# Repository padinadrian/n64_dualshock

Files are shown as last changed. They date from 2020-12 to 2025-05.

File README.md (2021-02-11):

# N64/DualShock

Author: Adrian Padin (padin.adrian@gmail.com)

Last updated: December 13, 2020

## Introduction

This repo contains the results of my work attempting to use a PlayStation 2 DualShock 2 controller with a Nintendo 64.

I used an [Adafruit Trinket Mini](https://learn.adafruit.com/introducing-trinket) to read from the DualShock controller, remap the buttons, and send the data to the N64.

Some of the tasks I accomplished along the way:

* Implementing the beginnings of a SPI library for the Trinket using the Atmel USI (Universal Serial Interface).

* Using bit-banging to read and write from the N64 using the N64's unique single-wire interface.

* Reprogramming the Trinket to use a modified bootloader which allows it to boot much faster.

You can read more about the N64, SPI, and other topics by checking out the resources below.

## Prototype

This is a picture of the prototype device:

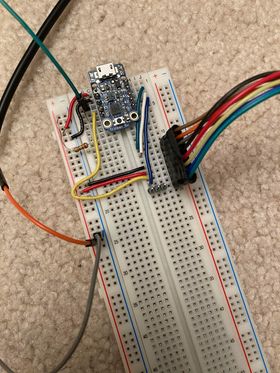
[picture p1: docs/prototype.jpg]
Prototype


Pin mapping:
* #0 - MISO (DualShock controller data)
* #1 - MOSI (DualShock controller command)
* #2 - SCLK (DualShock controller clock)
* #3 - SSEL (DualShock controller select)
* #4 - N64 data in/out

Here's a brief description of what's happening here:

* On the left, we have the power and ground lines. These are connected directly to the N64 controller's power, which is at 3.3V. This power line is fed into the VBAT pin on the Trinket. (In my prototype I used a 5V Trinket but I haven't noticed any issues).

* There are two GPIO pins on the left side of the board: #4 is used to communicate with the N64 and has a 22k pull-up resistor tied to the power line (since the N64 protocol is open-collector); and #3 (yellow wire in the picture) is the SPI select line.

* The three pins on the right side (green, white, and blue) are MISO, MOSI, and SCLK respectively. These connect to the PS2 controller, which is the large black connector on the bottom right.

## Resources

#### N64 Controller

In order to interface with the N64 I had to program the Trinket to behave like an N64 controller. Since the N64 uses such an odd custom protocol I used code from an [Instructables tutorial by quasse](https://www.instructables.com/Use-an-Arduino-with-an-N64-controller/) for reference.

(I did not copy the code directly since it is designed for interfacing with a controller, not the N64 console itself.)

There's also a great [tutorial by qwertymodo.com](http://www.qwertymodo.com/hardware-projects/n64/n64-controller) on reverse-engineering the N64 protocol which was very insightful, especially when it came to the data layer and remapping the button and joystick data.

#### PlayStation 2 / DualShock 2

I have lots of information on the PS2 controller in my `embedded_tools` library (see below).

#### embedded_tools

The embedded_tools library is a collection of convenient C++ utilities and libraries that I use across several of my projects. I'm continually developing it and adding functionality as I need it, but if you would like to use any part of it or contribute, you are more than welcome.

You can check out the [Github repository](https://github.com/padinadrian/embedded_tools) for more details.

#### ATTiny85 Bootloader

One of the issues I ran into in this project was boot time - the built-in Trinket firmware contains a bootloader that can take several seconds to boot, because it is searching for a USB connection to allow it to upload sketches.

After some digging online I found a bootloader (created by adafruit user hiduino) that allows you to skip the boot process if waking from a cold start, and only enters the bootloader when pressing the reset button. This allowed my code to start running almost immediately (under 100ms) instead of taking 2-3 seconds.

* Repairing or replacing bootloader:
  [https://learn.adafruit.com/introducing-trinket/repairing-bootloader](https://learn.adafruit.com/introducing-trinket/repairing-bootloader)

* New bootloader image:
  [https://forums.adafruit.com/viewtopic.php?f=52&t=54218&p=376898&hilit=trinket+bootloader+skip#p376898](https://forums.adafruit.com/viewtopic.php?f=52&t=54218&p=376898&hilit=trinket+bootloader+skip#p376898)

## To-Do

* Allow an attachable PS2 controller (instead of broken-out cheap controller).
  * https://www.amazon.com/PS2-Controller-Extension-Cable-Playstation-2/dp/B00005MDZ1

* Put together a more sturdy setup (PCB? or solder board?).

* Make a case (3D-printed maybe).

* Refactor and migrate N64-related code back into `embedded_tools`.

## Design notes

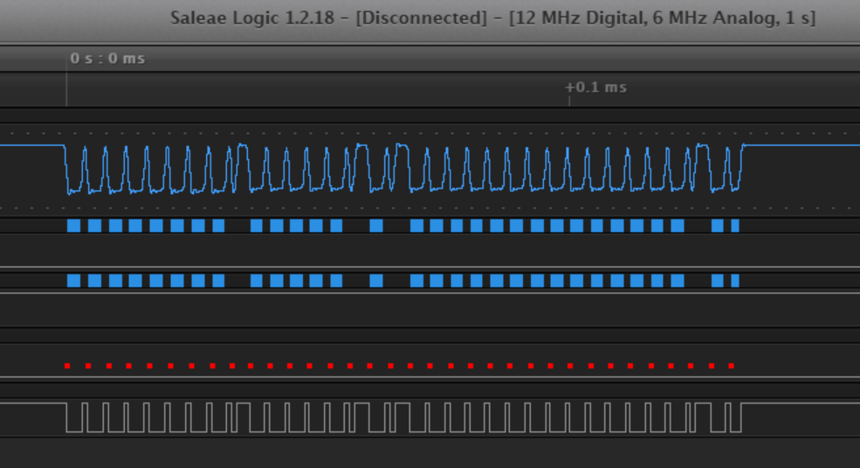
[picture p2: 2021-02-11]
docs/Captures/n64_oem_poll.png

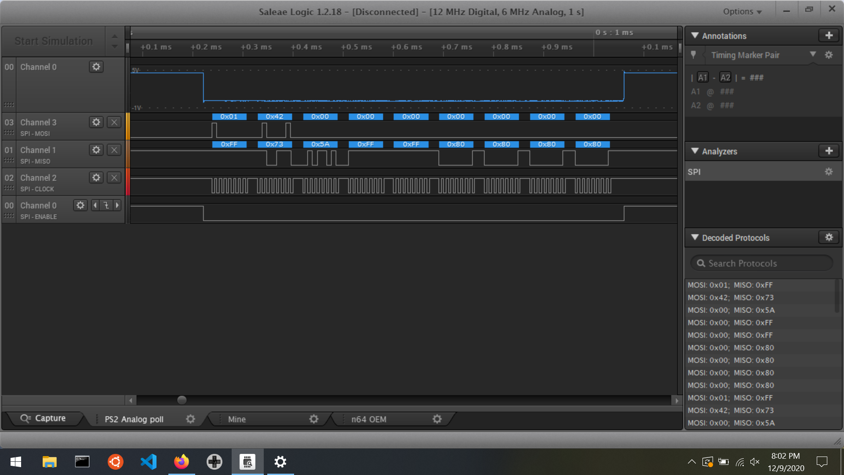
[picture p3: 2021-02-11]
docs/Captures/ps2_official.png

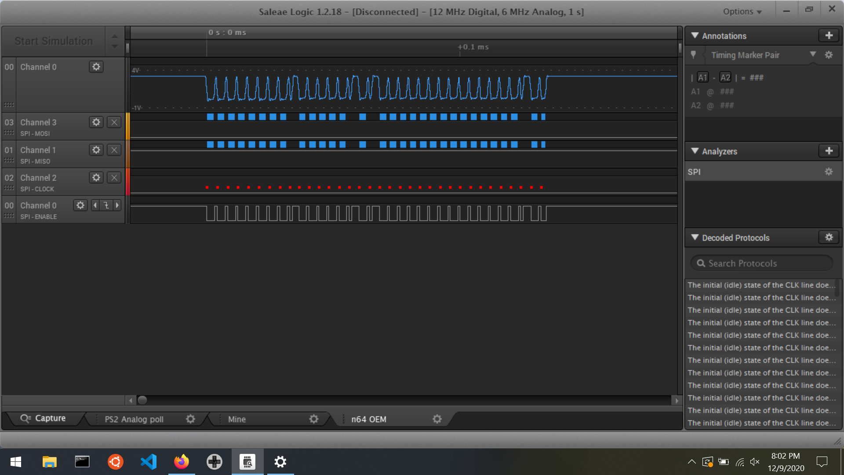
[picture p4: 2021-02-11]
docs/Captures/official.png

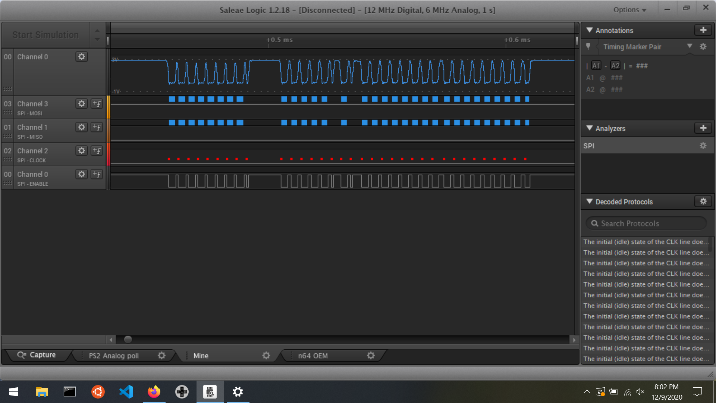
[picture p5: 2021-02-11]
docs/Captures/mine.png

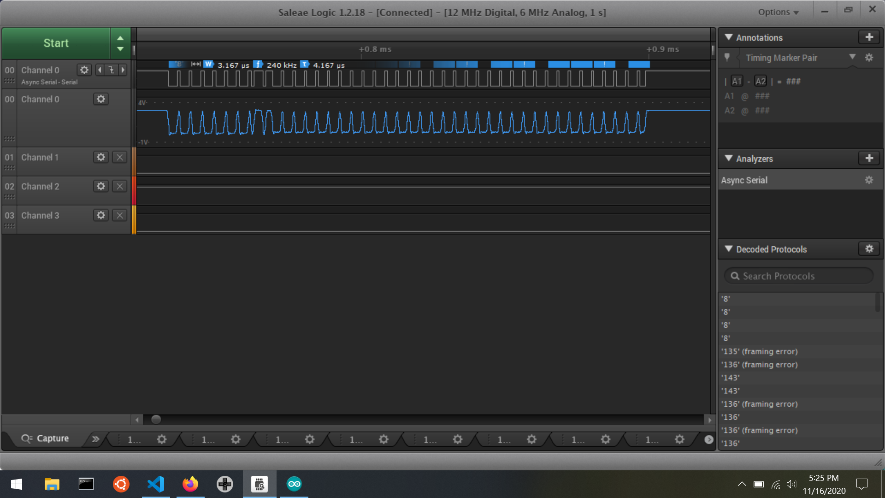
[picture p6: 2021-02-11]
docs/Captures/N64_screenshot1.png

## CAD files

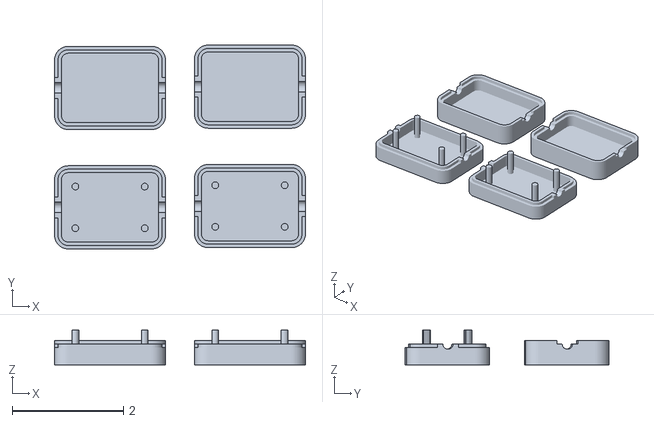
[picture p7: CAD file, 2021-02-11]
N64 DualShock (Final, inches).stl
4.52 x 3.67 x 0.625

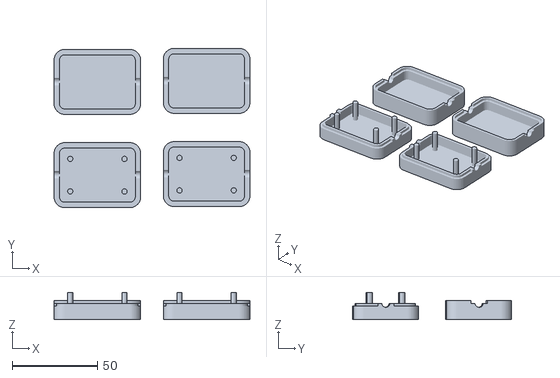
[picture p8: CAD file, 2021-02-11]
N64 DualShock (Final, millimeters).stl
114.8 x 93.3 x 15.9

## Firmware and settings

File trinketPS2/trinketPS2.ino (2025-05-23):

/**
 * File:    n64_dualshock.ino
 * Author:  padin.adrian@gmail.com
 *
 * Copyright 2019
 */

/* ===== Includes ====== */
#include "C:\\Users\\apadi\\Documents\\projects\\n64_dualshock\\trinketPS2\\button_translate.hpp"
#include "C:\\Users\\apadi\\Documents\\projects\\n64_dualshock\\trinketPS2\\N64.hpp"
#include "C:\\Users\\apadi\\Documents\\projects\\n64_dualshock\\embedded_tools/gpio/adrian_gpio_arduino.hpp"
#include "C:\\Users\\apadi\\Documents\\projects\\n64_dualshock\\embedded_tools/spi/adrian_spi_trinket.hpp"
#include "C:\\Users\\apadi\\Documents\\projects\\n64_dualshock\\embedded_tools/ps2/adrian_dualshock.hpp"
#include "C:\\Users\\apadi\\Documents\\projects\\n64_dualshock\\embedded_tools/n64/adrian_n64_console.hpp"

/* ===== Global ===== */

static adrian::TrinketSPI spi;
static adrian::ArduinoGPIO spi_select(3);
static adrian::DualShock controller(&spi, &spi_select);


/* ===== SETUP ===== */

void setup()
{
    spi_select.SetPinMode(OUTPUT);
    spi_select.Write(0);

    SingleWireInit();

    controller.EnableAnalog();
}


/* ===== LOOP ===== */

#define OUTPUT_BUFSIZE 4

static uint8_t input_buf = 0;
static uint8_t output_buf[OUTPUT_BUFSIZE] = { 0 };

static adrian::DualShock::ButtonState ps2_buttons;
static adrian::N64Controller::ButtonState n64_buttons;

static uint8_t status_buf[3] = { 0x05, 0x00, 0x02 };
static uint8_t read_response[33] = { 0 };

void loop()
{
    bool read_controller = false;

    noInterrupts();

    // Respond to commands from N64
    if (SingleWireRead(&input_buf, 1)) {
        switch (input_buf) {
            // Status
            case 0x00: {
                status_buf[1] = 0;
                SingleWireWrite(status_buf, sizeof(status_buf));
                read_controller = true;
                break;
            }
            // Poll
            case 0x01: {
                // output_buf[1] = input_buf;
                SingleWireWrite((uint8_t*)(&n64_buttons), sizeof(n64_buttons));
                read_controller = false;
                break;
            }
            // Read
            case 0x02: {
                SingleWireWrite(read_response, sizeof(read_response));
                break;
            }
            // Write
            case 0x03: {
                // TODO
                break;
            }
            default: {
                break;
                // This is for debugging SingleWireRead.
                // Echo back what you thought the command was.
                status_buf[1] = input_buf;
                SingleWireWrite(status_buf, sizeof(status_buf));
                break;
            }
        }
    }

    interrupts();

    // Poll from PS2 controller
    if (!controller.IsAnalogEnabled()) {
        controller.EnableAnalog();
    }
    else if (read_controller) {
        controller.Poll(ps2_buttons);
        read_controller = false;
    }

    if (ps2_buttons.analog_valid) {
        adrian::TranslateButtons(ps2_buttons, n64_buttons);
    }
    else {
        // Set all buttons and joysticks to zero
        memset((void *)(&n64_buttons), 0, sizeof(n64_buttons));
    }
}

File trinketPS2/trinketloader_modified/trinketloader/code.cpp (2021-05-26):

#include "optiLoader.h"

/*
 * Bootload images.
 * These are the intel Hex files produced by the optiboot makefile,
 * with a small amount of automatic editing to turn them into C strings,
 * and a header attched to identify them
 */

extern image_t *images[];
extern uint8_t NUMIMAGES;

/*
 * readSignature
 * read the bottom two signature bytes (if possible) and return them
 * Note that the highest signature byte is the same over all AVRs so we skip it
 */

uint16_t readSignature (void)
{
  SPI.setClockDivider(CLOCKSPEED_FUSES);

  uint16_t target_type = 0;
  Serial.print("\nReading signature:");

  target_type = spi_transaction(0x30, 0x00, 0x01, 0x00);
  target_type <<= 8;
  target_type |= spi_transaction(0x30, 0x00, 0x02, 0x00);

  Serial.println(target_type, HEX);
  if (target_type == 0 || target_type == 0xFFFF) {
    if (target_type == 0) {
      Serial.println("  (no target attached?)");
    }
  }
  return target_type;
}

/*
 * findImage
 *
 * given 'signature' loaded with the relevant part of the device signature,
 * search the hex images that we have programmed in flash, looking for one
 * that matches.
 */
image_t *findImage (uint16_t signature)
{
  image_t *ip;
  Serial.println("Searching for image...");

  for (byte i=0; i < NUMIMAGES; i++) {
    ip = images[i];

    if (ip && (pgm_read_word(&ip->image_chipsig) == signature)) {
	Serial.print("  Found \"");
	flashprint(&ip->image_name[0]);
	Serial.print("\" for ");
	flashprint(&ip->image_chipname[0]);
	Serial.println();

	return ip;
    }
  }
  Serial.println(" Not Found");
  return 0;
}

/*
 * programmingFuses
 * Program the fuse/lock bits
 */
boolean programFuses (const byte *fuses)
{
  SPI.setClockDivider(CLOCKSPEED_FUSES);

  byte f;
  Serial.print("\nSetting fuses");

  f = pgm_read_byte(&fuses[FUSE_PROT]);
  if (f) {
    Serial.print("\n  Set Lock Fuse to: ");
    Serial.print(f, HEX);
    Serial.print(" -> ");
    Serial.print(spi_transaction(0xAC, 0xE0, 0x00, f), HEX);
  }
  f = pgm_read_byte(&fuses[FUSE_LOW]);
  if (f) {
    Serial.print("  Set Low Fuse to: ");
    Serial.print(f, HEX);
    Serial.print(" -> ");
    Serial.print(spi_transaction(0xAC, 0xA0, 0x00, f), HEX);
  }
  f = pgm_read_byte(&fuses[FUSE_HIGH]);
  if (f) {
    Serial.print("  Set High Fuse to: ");
    Serial.print(f, HEX);
    Serial.print(" -> ");
    Serial.print(spi_transaction(0xAC, 0xA8, 0x00, f), HEX);
  }
  f = pgm_read_byte(&fuses[FUSE_EXT]);
  if (f) {
    Serial.print("  Set Ext Fuse to: ");
    Serial.print(f, HEX);
    Serial.print(" -> ");
    Serial.print(spi_transaction(0xAC, 0xA4, 0x00, f), HEX);
  }
  Serial.println();
  return true;			/* */
}

/*
 * verifyFuses
 * Verifies a fuse set
 */
boolean verifyFuses (const byte *fuses, const byte *fusemask)
{
  SPI.setClockDivider(CLOCKSPEED_FUSES);
  byte f;
  Serial.println(F("Verifying fuses..."));
  f = pgm_read_byte(&fuses[FUSE_PROT]);
  if (f) {
    uint8_t readfuse = spi_transaction(0x58, 0x00, 0x00, 0x00);  // lock fuse
    readfuse &= pgm_read_byte(&fusemask[FUSE_PROT]);
    Serial.print(F("\tLock Fuse: ")); Serial.print(f, HEX);  Serial.print(" is "); Serial.println(readfuse, HEX);
    if (readfuse != f)
      return false;
  }
  f = pgm_read_byte(&fuses[FUSE_LOW]);
  if (f) {
    uint8_t readfuse = spi_transaction(0x50, 0x00, 0x00, 0x00);  // low fuse
    Serial.print(F("\tLow Fuse: 0x"));  Serial.print(f, HEX); Serial.print(" is 0x"); Serial.println(readfuse, HEX);
    readfuse &= pgm_read_byte(&fusemask[FUSE_LOW]);
    if (readfuse != f)
      return false;
  }
  f = pgm_read_byte(&fuses[FUSE_HIGH]);
  if (f) {
    uint8_t readfuse = spi_transaction(0x58, 0x08, 0x00, 0x00);  // high fuse
    readfuse &= pgm_read_byte(&fusemask[FUSE_HIGH]);
    Serial.print(F("\tHigh Fuse: 0x"));  Serial.print(f, HEX); Serial.print(" is 0x");  Serial.println(readfuse, HEX);
    if (readfuse != f)
      return false;
  }
  f = pgm_read_byte(&fuses[FUSE_EXT]);
  if (f) {
    uint8_t readfuse = spi_transaction(0x50, 0x08, 0x00, 0x00);  // ext fuse
    readfuse &= pgm_read_byte(&fusemask[FUSE_EXT]);
    Serial.print("\tExt Fuse: 0x"); Serial.print(f, HEX); Serial.print(" is 0x"); Serial.println(readfuse, HEX);
    if (readfuse != f)
      return false;
  }
  Serial.println();
  return true;			/* */
}



/*
 * readImagePage
 *
 * Read a page of intel hex image from a string in pgm memory.
*/

// Returns number of bytes decoded
byte * readImagePage (byte *hextext, uint16_t pageaddr, uint8_t pagesize, byte *page)
{

  boolean firstline = true;
  uint16_t len;
  uint8_t page_idx = 0;
  byte *beginning = hextext;

  byte b, cksum = 0;

  //Serial.print("page size = "); Serial.println(pagesize, DEC);

  // 'empty' the page by filling it with 0xFF's
  for (uint8_t i=0; i<pagesize; i++)
    page[i] = 0xFF;

  while (1) {
    uint16_t lineaddr;

      // read one line!
    if (pgm_read_byte(hextext++) != ':') {
      error("No colon?");
      break;
    }
    // Read the byte count into 'len'
    len = hexton(pgm_read_byte(hextext++));
    len = (len<<4) + hexton(pgm_read_byte(hextext++));
    cksum = len;

    // read high address byte
    b = hexton(pgm_read_byte(hextext++));
    b = (b<<4) + hexton(pgm_read_byte(hextext++));
    cksum += b;
    lineaddr = b;

    // read low address byte
    b = hexton(pgm_read_byte(hextext++));
    b = (b<<4) + hexton(pgm_read_byte(hextext++));
    cksum += b;
    lineaddr = (lineaddr << 8) + b;

    if (lineaddr >= (pageaddr + pagesize)) {
      return beginning;
    }

    b = hexton(pgm_read_byte(hextext++)); // record type
    b = (b<<4) + hexton(pgm_read_byte(hextext++));
    cksum += b;
    //Serial.print("Record type "); Serial.println(b, HEX);
    if (b == 0x1) {
     // end record!
     break;
    }
#if VERBOSE
    Serial.print("\nLine address =  0x"); Serial.println(lineaddr, HEX);
    Serial.print("Page address =  0x"); Serial.println(pageaddr, HEX);
#endif
    for (byte i=0; i < len; i++) {
      // read 'n' bytes
      b = hexton(pgm_read_byte(hextext++));
      b = (b<<4) + hexton(pgm_read_byte(hextext++));

      cksum += b;
#if VERBOSE
      Serial.print(b, HEX);
      Serial.write(' ');
#endif

      page[page_idx] = b;
      page_idx++;

      if (page_idx > pagesize) {
          error("Too much code");
	  break;
      }
    }
    b = hexton(pgm_read_byte(hextext++));  // chxsum
    b = (b<<4) + hexton(pgm_read_byte(hextext++));
    cksum += b;
    if (cksum != 0) {
      error("Bad checksum: ");
      Serial.print(cksum, HEX);
    }
    if (pgm_read_byte(hextext++) != '\n') {
      error("No end of line");
      break;
    }
#if VERBOSE
    Serial.println();
    Serial.println(page_idx, DEC);
#endif
    if (page_idx == pagesize)
      break;
  }
#if VERBOSE
  Serial.print("\n  Total bytes read: ");
  Serial.println(page_idx, DEC);
#endif
  return hextext;
}
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

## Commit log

2019-07-20 New Arduino config and sketch files. Build not working.
2019-08-18 First fully working N64 example.
    * Finally able to read N64 controller button status reliably.
    * Created example ino file to demonstrate working behavior.
    * Minor updates to embedded_tools.
2019-09-13 Testing with Trinket as controller and Arduino as console.
2020-12-07 Most basic example is mostly working
    At this point I can press X on the PS2 controller and it
    registers as a button press on the N64. However we still
    need to complete the mapping for all buttons AND figure
    out analog joystick support.
    But things are looking good! :)
2020-12-08 More robust failure handling
    Changes:
    * Retry enabling analog on PS2 controller if it fails.
    * Handle more than just poll commands for N64 controller.
    * Proper button mapping and joystick translation.
    Almost everything is working from a happy-path scenario.
    Just need to fix some issues with failure cases and the
    software side of this is complete (feature-wise).
    [trinketPS2.ino]
2020-12-13 Slight adjustment to button mapping
2020-12-17 Fixing tests for button_translate
2020-12-17 More tests for button translate
2021-02-11 Finalize designs and modified bootloader
    * Bootloader code added to trinketloader_* folders (*modified is the
    version that will be used in the final version).
    * Captures taken while testing boot timing.
    * STL files of designs for the 3D printed the case.
    [N64 DualShock (Final, inches).stl, N64 DualShock (Final, millimeters).stl]
